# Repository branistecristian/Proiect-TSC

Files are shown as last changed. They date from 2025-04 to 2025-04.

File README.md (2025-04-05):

# OpenBook – E-Reader Hardware Project

OpenBook is an open-source e-reader built around the ESP32-C6, featuring a 7.5" e-Paper display, rechargeable battery, and Wi-Fi support. Designed for low-power embedded use and comfortable digital reading.

---

##  Block Diagram

`Images/block_diagram.png`

> Diagram shows how ESP32-C6 is connected to display, battery, charging module, and buttons.

---

## 📋 Bill of Materials (BOM)

| Reference | Value | Device | Footprint | Description | Link |
|:---|:---|:---|:---|:---|:---|
| BOOT_BUTTON  | BUTTON_CUSYOMV1  | BUTTON_CUSYOMV1 | MYBUTTON | - | https://industry.panasonic.com/global/en/products/control/switch/light-touch/number/evqpuj02k |
| C1 | 100nF | ESP32_WROVER_EAGLE-LTSPICE_CC0402 | C0402 | CAPACITOR, European symbol | https://componentsearchengine.com/part-view/CC0402MRX5R5BB106/YAGEO |
| C2 | 100nF | ESP32_WROVER_EAGLE-LTSPICE_CC0402 | C0402 | CAPACITOR, European symbol | |
| C3 | 100uF TANT | RCL_CPOL-EUCT3528 | CT3528 | POLARIZED CAPACITOR | |
| C10_SUPERCAP | CPH3225A | CPH3225A | CAPCP3225X100N | 11 mF (EDLC) Supercapacitor 3.3V | https://www.snapeda.com/parts/CPH3225A/Seiko+Instruments/view-part/?ref=eda |
| CHG_LED | - | ADAFRUIT_LEDCHIP-LED0603 | LED0603 | LED | https://www.snapeda.com/parts/KP-1608SURCK/Kingbright/view-part/?ref=search&t=LED |
| D1 | USBLC6-2SC6Y | USBLC6-2SC6Y | SOT23-6 | TVS Diode Array | https://www.snapeda.com/parts/USBLC6-2SC6Y/STMicroelectronics/view-part/?ref=eda |
| D2 | - | AVX_SD0805S020S1R0 | 0805 | Schottky Diode | https://eu.mouser.com/ProductDetail/KYOCERA-AVX/SD0805S020S1R0 |
| D3 | MBR0530 | MBR0530 | SOD123 | Schottky Diode | https://www.snapeda.com/parts/MBR0530/Onsemi/view-part/?ref=eda |
| D4 | MBR0530 | MBR0530 | SOD123 | Schottky Diode | https://www.snapeda.com/parts/MBR0530/Onsemi/view-part/?ref=eda |
| D5 | MBR0530 | MBR0530 | SOD123 | Schottky Diode | https://www.snapeda.com/parts/MBR0530/Onsemi/view-part/?ref=eda |
| D6 | PGB1010603MR | PGB1010603MR | 0603 | TVS Diode Clamp | https://www.snapeda.com/parts/PGB1010603MR/Littelfuse/view-part/?ref=eda |
| D7 | - | AVX_SD0805S020S1R0 | 0805 | Schottky Diode | https://eu.mouser.com/ProductDetail/KYOCERA-AVX/SD0805S020S1R0 |
| D8 | PGB1010603MR | PGB1010603MR | 0603 | TVS Diode Clamp | https://www.snapeda.com/parts/PGB1010603MR/Littelfuse/view-part/?ref=eda |
| D9 | PGB1010603MR | PGB1010603MR | 0603 | TVS Diode Clamp | https://www.snapeda.com/parts/PGB1010603MR/Littelfuse/view-part/?ref=eda |
| D10 | PGB1010603MR | PGB1010603MR | 0603 | TVS Diode Clamp | https://www.snapeda.com/parts/PGB1010603MR/Littelfuse/view-part/?ref=eda |
| D11 | PGB1010603MR | PGB1010603MR | 0603 | TVS Diode Clamp | https://www.snapeda.com/parts/PGB1010603MR/Littelfuse/view-part/?ref=eda |
| IC1 | BD5229G-TR | BD5229G-TR | SOT23-5 | Voltage Detector | https://componentsearchengine.com/part-view/BD5229G-TR/ROHM%20Semiconductor |
| IC4 | XC6220A331MR-G | XC6220A331MR-G | SOT23-5 | LDO Regulator | https://componentsearchengine.com/part-view/XC6220A331MR-G/Torex |
| J1 | FFC 24P | FH34SRJ-24S-0.5SH | 0.5mm Pitch | FFC/FPC Connector | https://componentsearchengine.com/part-view/FH34SRJ-24S-0.5SH(99)/Hirose |
| J2 | USB-C | USB4110-GF-A | USB4110 | USB Type-C Connector | https://componentsearchengine.com/part-view/USB4110-GF-A/GCT%20(GLOBAL%20CONNECTOR%20TECHNOLOGY) |
| J3 | QWIIC | QWIIC_CONNECTORJS-1MM | JST04 | QWIIC I2C Connector | |
| J4 | SD Card | 112A-TAAR-R03_ATTEND | MicroSD | MicroSD Socket | https://store.comet.srl.ro/Catalogue/Product/43497/ |
| L1 | 68uH | 744043680 | IND_4828 | Power Inductor | https://eu.mouser.com/ProductDetail/Wurth-Elektronik/744043680 |
| PFMF.050.1 | - | ESP32C6_VARISTOR | 1812 | Varistor | https://www.mouser.co.uk/ProductDetail/EPCOS-TDK/B72520T0350K062 |
| Q1 | - | DMG2305UX-7 | SOT23 | P-channel MOSFET | https://componentsearchengine.com/part-view/DMG2305UX-7/Diodes%20Incorporated |
| Q2 | - | DMG2305UX-7 | SOT23 | P-channel MOSFET | |
| Q3 | SI1308EDL-T1-GE3 | SI1308EDL | SC70 | N-channel MOSFET | https://componentsearchengine.com/part-view/SI1308EDL-T1-GE3/Vishay |
| R1 | 10K | ESP32_WROVER_EAGLE-LTSPICE_RR0402 | R0402 | RESISTOR | |
| R2 | 2.2 | ESP32_WROVER_EAGLE-LTSPICE_RR0402 | R0402 | RESISTOR | https://componentsearchengine.com/part-view/R0402%201%25%20100%20K%20(RC0402FR-07100KL)/YAGEO |

---

##  Detailed Hardware Functionality

###  Power System
- 3.7V 1800mAh Li-Po Battery (Cellevia LP584174)
- Charged via TP4056 USB module
- 3.3V provided via AMS1117 LDO regulator

###  Display
- Waveshare 7.5" e-Paper V2, SPI interface
- 800x480 resolution, ultra-low power
- Controlled by ESP32-C6 using GPIOs

###  Microcontroller – ESP32-C6
- BLE 5 + Wi-Fi 6
- Handles display updates and user input
- SPI + UART + GPIO used

###  Estimated Power Budget
| State | Current | Est. Battery Life (1800mAh) |
|---|---|---|
| Idle | ~20mA | ~90 hours |
| Display Update  | ~120mA  | ~12–15 hours |

##  ESP32-C6 Pin Mapping

| Feature | ESP32-C6 Pin | Description |
|---|---|---|
| SPI CLK | GPIO6 | Display SCK |
| SPI MOSI | GPIO7 | Display data |
| Display CS | GPIO10 | Chip select |
| Display DC | GPIO5 | Command/data |
| Display RST | GPIO4 | Reset |
| Display BUSY | GPIO3 | Ready state |
| Button A | GPIO0 | Pull-down |
| Button B | GPIO1 | Pull-down |
| UART TX | GPIO21 | Debug |
| UART RX | GPIO20 | Debug |

---

##  Renders & Images

 See `Images/` folder:
- `render_device.png` – Full device
- `render_pcb.png` – PCB only
- `block_diagram.png` – System layout

---

##  Design Notes
- All components were placed in Fusion 360 with correct dimensions
- PCB designed in Eagle + validated via 3D overlay
- Gerbers, BOM, and Pick & Place ready for fab
- Fusion file exported as both `.step` and `.f3d`

---

## Credits

Made with CAD, curse words, and caffeine.

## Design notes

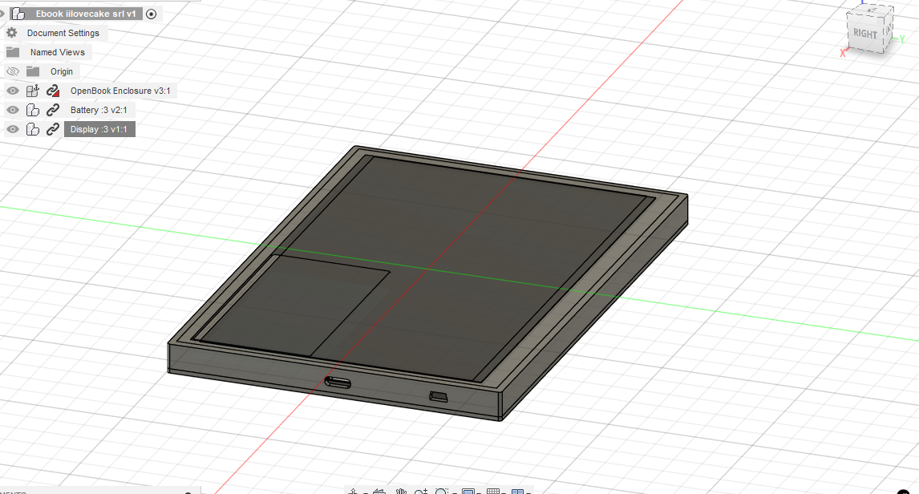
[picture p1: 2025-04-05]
Images/render_device.png

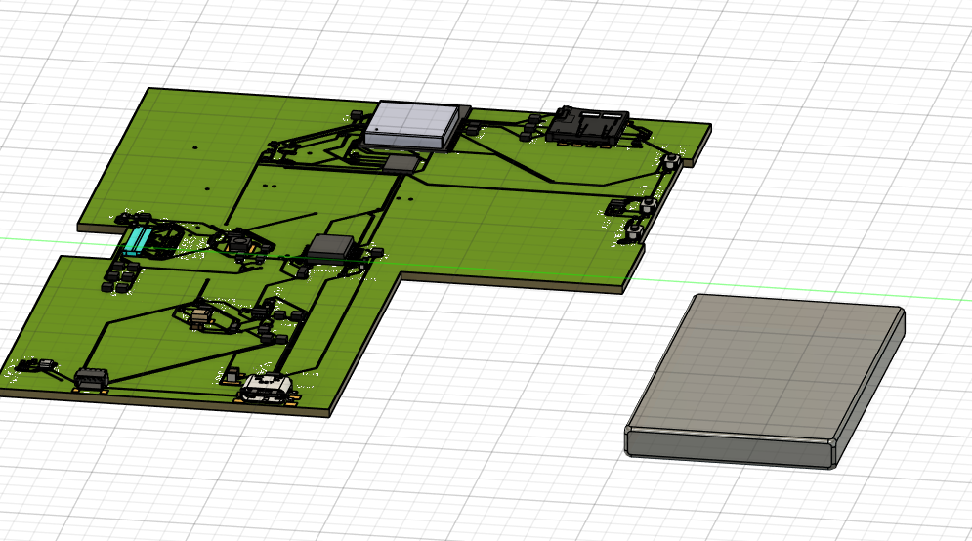
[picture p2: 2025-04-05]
Images/render_exploded.png

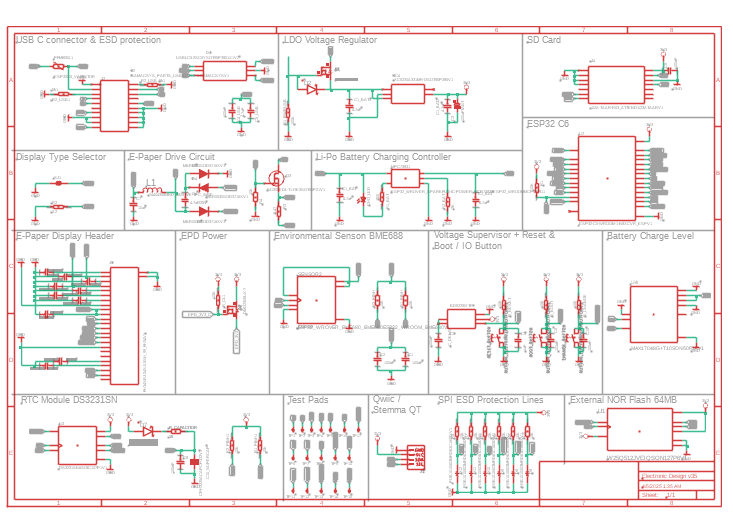
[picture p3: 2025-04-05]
Images/render_sch.png

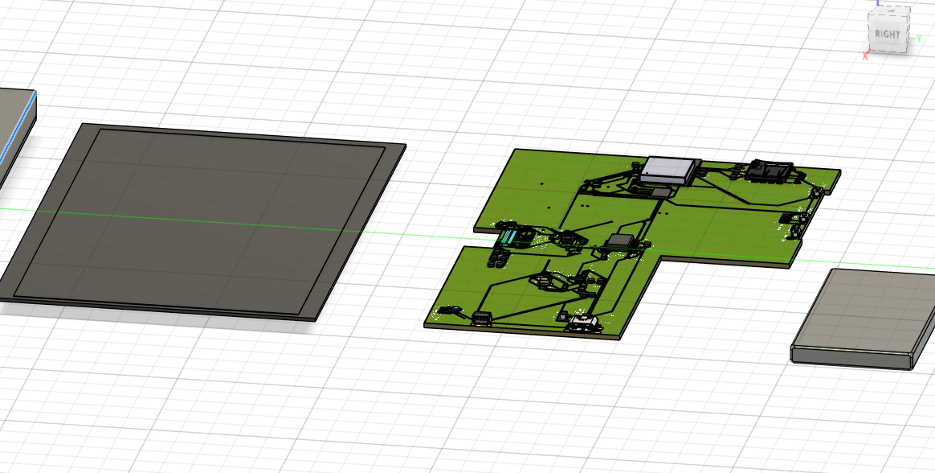
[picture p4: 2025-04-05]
Images/render_exploded1.png

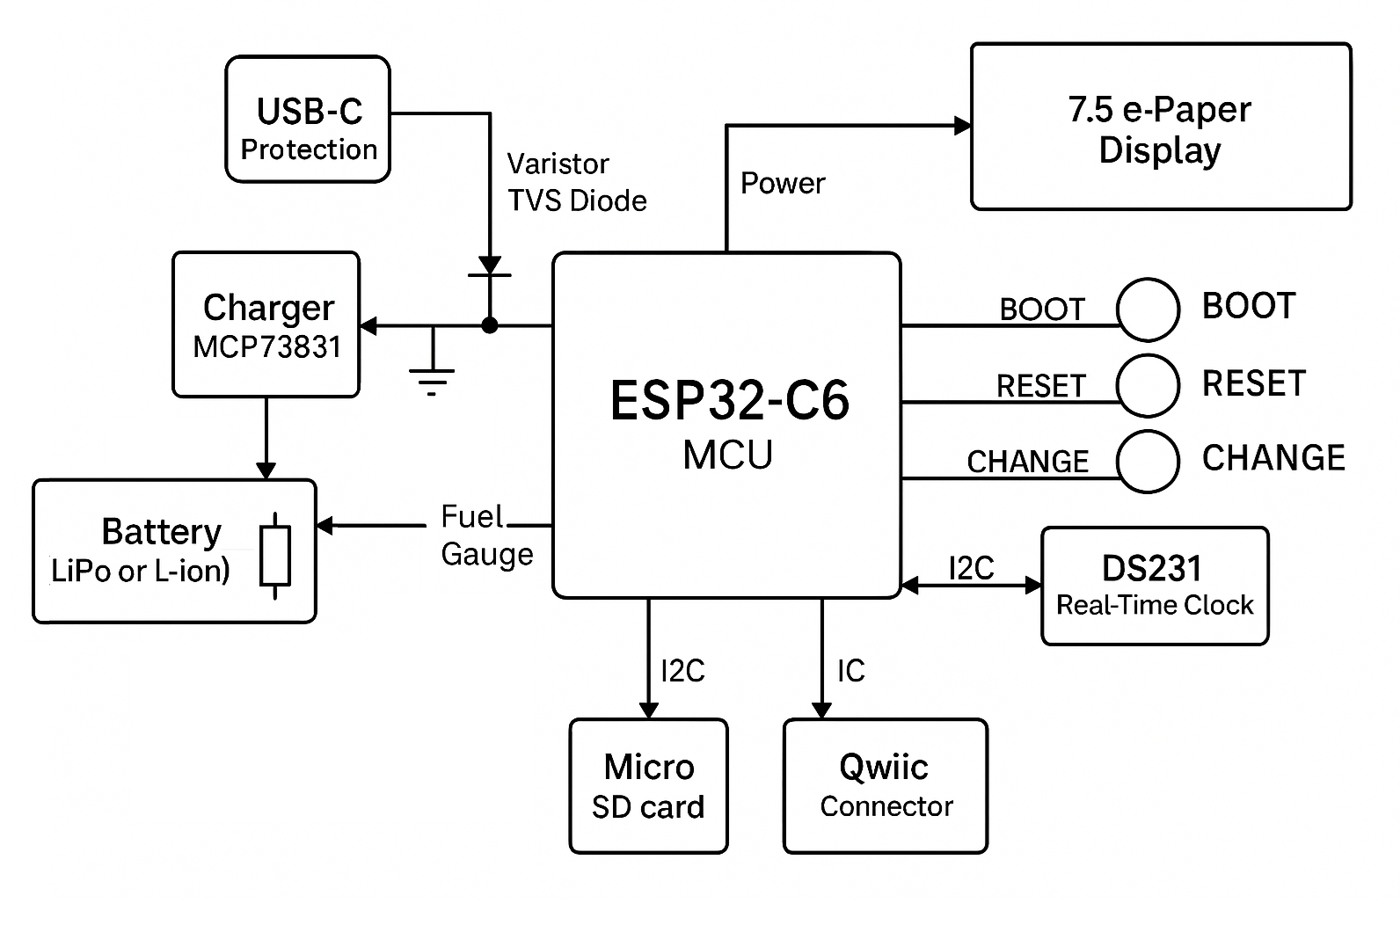
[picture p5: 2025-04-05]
Images/block_diagram.png

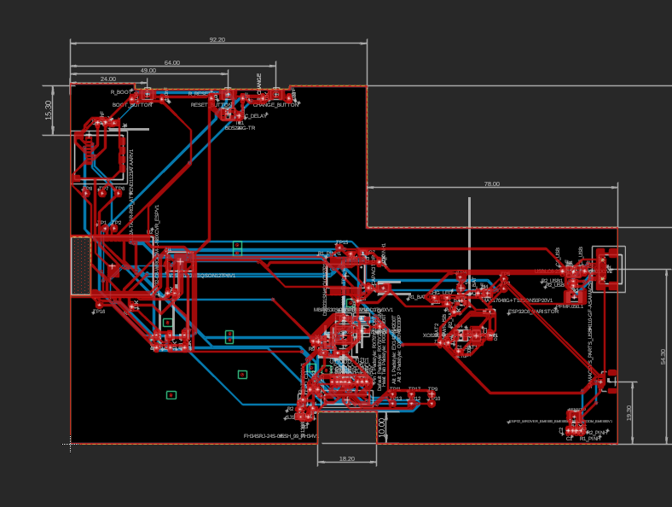
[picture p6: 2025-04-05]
Images/render_pcb.png

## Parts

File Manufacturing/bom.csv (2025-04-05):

Part | Value | Device | Footprint Name | Detailed Description | POPULARITY | SPICEMODEL | SPICEPREFIX | TP_SIGNAL_NAME
BOOT_BUTTON | BUTTON_CUSYOMV1MYBUTTONV1 | BUTTON_CUSYOMV1MYBUTTONV1 | MYBUTTON
C1 | 100nF | EAGLE-LTSPICE_CC0402 | EAGLE-LTSPICE_C0402 | CAPACITOR, European symbol |  | NONE | C
C1_BAT | 4.7uF | ESP32_WROVER_EAGLE-LTSPICE_C | ESP32_WROVER_EAGLE-LTSPICE_C0402 | CAPACITOR, European symbol
C1_BAT1 | 4.7uF | ESP32_WROVER_EAGLE-LTSPICE_C | ESP32_WROVER_EAGLE-LTSPICE_C0402 | CAPACITOR, European symbol
C1_BAT2 | 4.7uF | ESP32_WROVER_EAGLE-LTSPICE_C | ESP32_WROVER_EAGLE-LTSPICE_C0402 | CAPACITOR, European symbol
C2 | 100nF | EAGLE-LTSPICE_CC0402 | EAGLE-LTSPICE_C0402 | CAPACITOR, European symbol |  | NONE | C
C2_BAT | 4.7uF | ESP32_WROVER_EAGLE-LTSPICE_C | ESP32_WROVER_EAGLE-LTSPICE_C0402 | CAPACITOR, European symbol
C3 | 100uF TANT | RCL_CPOL-EU | RCL_CT3528 | POLARIZED CAPACITOR, European symbol
C4 | 4.7uF/25V | ESP32_WROVER_EAGLE-LTSPICE_C | ESP32_WROVER_EAGLE-LTSPICE_C0402 | CAPACITOR, European symbol
C4_USB | 100nF | ESP32_WROVER_EAGLE-LTSPICE_C | ESP32_WROVER_EAGLE-LTSPICE_C0402 | CAPACITOR, European symbol
C5 | 1uF | EAGLE-LTSPICE_CC0402 | EAGLE-LTSPICE_C0402 | CAPACITOR, European symbol |  | NONE | C
C5_USB | 4.7uF | ESP32_WROVER_EAGLE-LTSPICE_C | ESP32_WROVER_EAGLE-LTSPICE_C0402 | CAPACITOR, European symbol
C6 | 100nF | EAGLE-LTSPICE_CC0402 | EAGLE-LTSPICE_C0402 | CAPACITOR, European symbol |  | NONE | C
C7 | 10uF | ESP32_WROVER_EAGLE-LTSPICE_C | ESP32_WROVER_EAGLE-LTSPICE_C0402 | CAPACITOR, European symbol
C8 | 100nF | EAGLE-LTSPICE_CC0402 | EAGLE-LTSPICE_C0402 | CAPACITOR, European symbol |  | NONE | C
C9 | 100nF | ESP32_WROVER_EAGLE-LTSPICE_C | ESP32_WROVER_EAGLE-LTSPICE_C0402 | CAPACITOR, European symbol
C10 | 100nF | EAGLE-LTSPICE_CC0402 | EAGLE-LTSPICE_C0402 | CAPACITOR, European symbol |  | NONE | C
C10_SUPERCAP | CPH3225ACAPCP322V1 | CPH3225ACAPCP322V1 | CAPCP3225X100N | Cap 0.011F 3.3V 1210 Flat Check availability
CHANGE_BUTTON | BUTTON_CUSYOMV1MYBUTTONV1 | BUTTON_CUSYOMV1MYBUTTONV1 | MYBUTTON
CHG_LED |  | ADAFRUIT_LED | ADAFRUIT_CHIP-LED0603 | LED
C_DELAY | 100nF | EAGLE-LTSPICE_CC0402 | EAGLE-LTSPICE_C0402 | CAPACITOR, European symbol |  | NONE | C
D1 | USBLC6-2SC6YSOT95P2801X1V2 | USBLC6-2SC6YSOT95P2801X1V2 | SOT95P280X145-6N | Low Cap. ESD Protection Auto SOT-23-6 STMicroelectronics USBLC6-2SC6Y, Dual Uni-Directional TVS Diode Array, 6-Pin SOT-23
D2 | ESP32_WROVER_AVX---SD0805S020S1R0_AVX_SD0805S020S1R0_0_0 | ESP32_WROVER_AVX---SD0805S020S1R0_AVX_SD0805S020S1R0_0_0 | ESP32_WROVER_AVX---SD0805S020S1R0_AVX_SD0805S020S1R0_0 | Schottky Barrier Rectifier Diode
D3 | MBR0530SOD3716XV1 | MBR0530SOD3716XV1 | SOD3716X135N | ON SEMICONDUCTOR - MBR0530 - DIODE, SCHOTTKY, 0.5A, 30V, SOD-123
D4 | MBR0530SOD3716XV1 | MBR0530SOD3716XV1 | SOD3716X135N | ON SEMICONDUCTOR - MBR0530 - DIODE, SCHOTTKY, 0.5A, 30V, SOD-123
D5 | MBR0530SOD3716XV1 | MBR0530SOD3716XV1 | SOD3716X135N | ON SEMICONDUCTOR - MBR0530 - DIODE, SCHOTTKY, 0.5A, 30V, SOD-123
D6 | PGB1010603MRDIOC1608XV1 | PGB1010603MRDIOC1608XV1 | DIOC1608X36N | Check availability
D7 | ESP32_WROVER_AVX---SD0805S020S1R0_AVX_SD0805S020S1R0_0_0 | ESP32_WROVER_AVX---SD0805S020S1R0_AVX_SD0805S020S1R0_0_0 | ESP32_WROVER_AVX---SD0805S020S1R0_AVX_SD0805S020S1R0_0 | Schottky Barrier Rectifier Diode
D8 | PGB1010603MRDIOC1608XV1 | PGB1010603MRDIOC1608XV1 | DIOC1608X36N | Check availability
D9 | PGB1010603MRDIOC1608XV1 | PGB1010603MRDIOC1608XV1 | DIOC1608X36N | Check availability
D10 | PGB1010603MRDIOC1608XV1 | PGB1010603MRDIOC1608XV1 | DIOC1608X36N | Check availability
D11 | PGB1010603MRDIOC1608XV1 | PGB1010603MRDIOC1608XV1 | DIOC1608X36N | Check availability
D12 | PGB1010603MRDIOC1608XV1 | PGB1010603MRDIOC1608XV1 | DIOC1608X36N | Check availability
EPD_C1 | 1uF/50V | EAGLE-LTSPICE_CC0402 | EAGLE-LTSPICE_C0402 | CAPACITOR, European symbol |  | NONE | C
EPD_C2 | 1uF/50V | EAGLE-LTSPICE_CC0402 | EAGLE-LTSPICE_C0402 | CAPACITOR, European symbol |  | NONE | C
EPD_C5 | 0.1uF/50V | EAGLE-LTSPICE_CC0402 | EAGLE-LTSPICE_C0402 | CAPACITOR, European symbol |  | NONE | C
EPD_C6 | 1uF/50V | EAGLE-LTSPICE_CC0402 | EAGLE-LTSPICE_C0402 | CAPACITOR, European symbol |  | NONE | C
EPD_C7 | 1uF/50V | EAGLE-LTSPICE_CC0402 | EAGLE-LTSPICE_C0402 | CAPACITOR, European symbol |  | NONE | C
EPD_C8 | 1uF/50V | EAGLE-LTSPICE_CC0402 | EAGLE-LTSPICE_C0402 | CAPACITOR, European symbol |  | NONE | C
EPD_C9 | 1uF/50V | EAGLE-LTSPICE_CC0402 | EAGLE-LTSPICE_C0402 | CAPACITOR, European symbol |  | NONE | C
EPD_C10 | 1uF/50V | EAGLE-LTSPICE_CC0402 | EAGLE-LTSPICE_C0402 | CAPACITOR, European symbol |  | NONE | C
EPD_C11 | 1uF/50V | EAGLE-LTSPICE_CC0402 | EAGLE-LTSPICE_C0402 | CAPACITOR, European symbol |  | NONE | C
EPD_C12 | 1uF/50V | EAGLE-LTSPICE_CC0402 | EAGLE-LTSPICE_C0402 | CAPACITOR, European symbol |  | NONE | C
IC1 | BD5229G-TR | BD5229G-TR | SOT95P280X120-5N | Voltage Detector with Adjustable Delay Time: CMOS processes are utilized to develop high precision, low current consumption CMOS reset ICs that allow arbitrary setting of the delay time. The extensive lineup includes both Nch Open Drain and CMOS output types in a wide range of detection voltages (from 2.3V to 6.0V, in 0.1V steps), enabling selection of the ideal solution based on customer requirements. In addition, the entire series is of course both lead-free and RoHS-compliant.
IC4 | XC6220A331MR-GSOT95P285V1 | XC6220A331MR-GSOT95P285V1 | SOT95P280X120-5N | LDO Voltage Regulators
J1 | FH34SRJ-24S-0.5SH_99_FH34V1 | FH34SRJ-24S-0.5SH_99_FH34V1 | FH34SRJ24S05SH99 | 24 Position FFC, FPC Connector Contacts, Top and Bottom 0.020 (0.50mm) Surface Mount, Right Angle"
J2 | SAMACSYS_PARTS_USB4110-GF-ASAMACSYSV1 | SAMACSYS_PARTS_USB4110-GF-ASAMACSYSV1 | SAMACSYS_PARTS_USB4110GFA | CONN USB 2.0 TYPE-C R/A SMT
J3 | QWIIC_RIGHT_ANGLE | QWIIC_CONNECTOR | JST04_1MM_RA | SparkFun I2C Standard Qwiic Connector
J4 | 112A-TAAR-R03_ATTEND1123ATAARV1 | 112A-TAAR-R03_ATTEND1123ATAARV1 | 112ATAARR03ATTEND | Micro SD Card Socket, Push-Push Type, Top Mount, SMT, H=1.83mm, 10u
L1 | 744043680IND_4828-WE-TPC_WRE | 744043680 | IND_4828-WE-TPC_WRE
MPC73831 | ESP32_WROVER_SPARKFUN-IC-POWER_MCP73831ESP32_WROOMMCP673811 | ESP32_WROVER_SPARKFUN-IC-POWER_MCP73831ESP32_WROOMMCP673811 | ESP32_WROVER_SPARKFUN-IC-POWER_SOT23-5 | MCP73831T Li-Ion, Li-Pol Controller
PFMF.050.1 | ESP32C6_VARISTOR | ESP32C6_VARISTOR | ESP32C6_VARISTOR_CT/CN1812 | VARISTOR
Q1 | 20V/4.2A/52mO/1.4W | ESP32_WROVER_SPARKFUN-DISCRETESEMI_MOSFET_PCH | ESP32_WROVER_SPARKFUN-DISCRETESEMI_SOT23-3 | P-channel MOSFETs
Q2 | 20V/4.2A/52mO/1.4W | ESP32_WROVER_SPARKFUN-DISCRETESEMI_MOSFET_PCH | ESP32_WROVER_SPARKFUN-DISCRETESEMI_SOT23-3 | P-channel MOSFETs
Q3 | SI1308EDL-T1-GE3SOT65P21V1 | SI1308EDL-T1-GE3SOT65P21V1 | SOT65P210X110-3N | MOSFET N-Ch 30V 1.5A TrenchFET SC70 Vishay Si1308EDL-T1-GE3 N-channel MOSFET Transistor, 1.5 A, 30 V, 3-Pin SC-70
R1 | 10K | ESP32_WROVER_EAGLE-LTSPICE_R | ESP32_WROVER_EAGLE-LTSPICE_R0402 | RESISTOR, European symbol
R1_BAT | 200 | ESP32_WROVER_EAGLE-LTSPICE_R | ESP32_WROVER_EAGLE-LTSPICE_R0402 | RESISTOR, European symbol
R1_PINH | 10K | ESP32_WROVER_EAGLE-LTSPICE_R | ESP32_WROVER_EAGLE-LTSPICE_R0402 | RESISTOR, European symbol
R1_PINH1 | 10K | ESP32_WROVER_EAGLE-LTSPICE_R | ESP32_WROVER_EAGLE-LTSPICE_R0402 | RESISTOR, European symbol
R1_PWRUSB | 100K | ESP32_WROVER_EAGLE-LTSPICE_R | ESP32_WROVER_EAGLE-LTSPICE_R0402 | RESISTOR, European symbol
R2 | 2.2 | ESP32_WROVER_EAGLE-LTSPICE_R | ESP32_WROVER_EAGLE-LTSPICE_R0402 | RESISTOR, European symbol
R2_BAT | 2K | ESP32_WROVER_EAGLE-LTSPICE_R | ESP32_WROVER_EAGLE-LTSPICE_R0402 | RESISTOR, European symbol
R2_PINH | 10K | ESP32_WROVER_EAGLE-LTSPICE_R | ESP32_WROVER_EAGLE-LTSPICE_R0402 | RESISTOR, European symbol
R2_PINH1 | 10K | ESP32_WROVER_EAGLE-LTSPICE_R | ESP32_WROVER_EAGLE-LTSPICE_R0402 | RESISTOR, European symbol
R2_USB | 5k1 | ESP32_WROVER_EAGLE-LTSPICE_R | ESP32_WROVER_EAGLE-LTSPICE_R0402 | RESISTOR, European symbol
R2_USB1 | 5k1 | ESP32_WROVER_EAGLE-LTSPICE_R | ESP32_WROVER_EAGLE-LTSPICE_R0402 | RESISTOR, European symbol
R3 | 0.47 | ESP32_WROVER_EAGLE-LTSPICE_R | ESP32_WROVER_EAGLE-LTSPICE_R0402 | RESISTOR, European symbol
R4 | 10K | ESP32_WROVER_EAGLE-LTSPICE_R | ESP32_WROVER_EAGLE-LTSPICE_R0402 | RESISTOR, European symbol
R5 | 10K | ESP32_WROVER_EAGLE-LTSPICE_R | ESP32_WROVER_EAGLE-LTSPICE_R0402 | RESISTOR, European symbol
R6 | 10K | ESP32_WROVER_EAGLE-LTSPICE_R | ESP32_WROVER_EAGLE-LTSPICE_R0402 | RESISTOR, European symbol
R7 | 10K | ESP32_WROVER_EAGLE-LTSPICE_R | ESP32_WROVER_EAGLE-LTSPICE_R0402 | RESISTOR, European symbol
R8 | 10K | ESP32_WROVER_EAGLE-LTSPICE_R | ESP32_WROVER_EAGLE-LTSPICE_R0402 | RESISTOR, European symbol
R9 | 10K | ESP32_WROVER_EAGLE-LTSPICE_R | ESP32_WROVER_EAGLE-LTSPICE_R0402 | RESISTOR, European symbol
R10 | 10K | ESP32_WROVER_EAGLE-LTSPICE_R | ESP32_WROVER_EAGLE-LTSPICE_R0402 | RESISTOR, European symbol
RESET_BUTTON | BUTTON_CUSYOMV1MYBUTTONV1 | BUTTON_CUSYOMV1MYBUTTONV1 | MYBUTTON
R_BOOT | 10K | ESP32_WROVER_EAGLE-LTSPICE_R | ESP32_WROVER_EAGLE-LTSPICE_R0402 | RESISTOR, European symbol
R_CAPACITOR | 15 | ESP32_WROVER_EAGLE-LTSPICE_R | ESP32_WROVER_EAGLE-LTSPICE_R0402 | RESISTOR, European symbol
R_CHANGE | 10K | ESP32_WROVER_EAGLE-LTSPICE_R | ESP32_WROVER_EAGLE-LTSPICE_R0402 | RESISTOR, European symbol
R_CL1 | 10K | ESP32_WROVER_EAGLE-LTSPICE_R | ESP32_WROVER_EAGLE-LTSPICE_R0402 | RESISTOR, European symbol
R_RESET | 10K | ESP32_WROVER_EAGLE-LTSPICE_R | ESP32_WROVER_EAGLE-LTSPICE_R0402 | RESISTOR, European symbol
SENSOR2 | ESP32_WROVER_BME680_BME680ESP32_WROOM_BME680V1 | ESP32_WROVER_BME680_BME680ESP32_WROOM_BME680V1 | ESP32_WROVER_BME680_PSON80P300X300X100-8N | Integrated Environmental Unit
SJ1 |  | SJSJV1 | SJ | SMD solder JUMPER
TP1 | TPTP20R | TPTP20R | TP20R | Test pad | 2
TP2 | TPTP20R | TPTP20R | TP20R | Test pad | 2
TP3 | TPTP20R | TPTP20R | TP20R | Test pad | 2
TP4 | TPTP20R | TPTP20R | TP20R | Test pad | 2
TP5 | TPTP20R | TPTP20R | TP20R | Test pad | 2
TP6 | TPTP20R | TPTP20R | TP20R | Test pad | 2
TP7 | TPTP20R | TPTP20R | TP20R | Test pad | 2
TP8 | TPTP20R | TPTP20R | TP20R | Test pad | 2
TP9 | TPTP20R | TPTP20R | TP20R | Test pad | 2
TP10 | TPTP20R | TPTP20R | TP20R | Test pad | 2
TP11 | TPTP20R | TPTP20R | TP20R | Test pad | 2
TP12 | TPTP20R | TPTP20R | TP20R | Test pad | 2
TP13 | TPTP20R | TPTP20R | TP20R | Test pad | 2
TP14 | TPTP20R | TPTP20R | TP20R | Test pad | 2
TP15 | TPTP20R | TPTP20R | TP20R | Test pad | 2
TP16 | TPTP20R | TPTP20R | TP20R | Test pad | 2
TP17 | TPTP20R | TPTP20R | TP20R | Test pad | 2
U1 | W25Q512JVEIQSON127P6V1 | W25Q512JVEIQSON127P6V1 | SON127P600X800X80-9N | Check availability
U2 | ESP32-C6-WROOM-1-N8XCVR_ESPV1 | ESP32-C6-WROOM-1-N8XCVR_ESPV1 | XCVR_ESP32-C6-WROOM-1-N8 | Check availability
U3 | DS3231SN#SOIC127P1V1 | DS3231SN#SOIC127P1V1 | SOIC127P1032X265-16N | Real Time Clock Serial 16-Pin SOIC W T/R Check availability
U4 | MAX17048G+T10SON50P20V1 | MAX17048G+T10SON50P20V1 | SON50P200X200X80-9N | Check availability

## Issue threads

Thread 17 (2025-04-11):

Probleme cu denumirile silkscreen-ului

HoriaMoroianu, 2025-04-11:
Layer-ul de silkscreen nu este citet, iar test pad-urile nu sunt marcate cu numele semnalelor corespunzătoare.

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

Closed 2025-04-14.

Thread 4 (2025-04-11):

Clarificare conținut BOM

HoriaMoroianu, 2025-04-11:
BOM-ul din README ar trebui să includă doar componentele sau modulele utilizate, împreună cu link-uri către sursele de achiziție și datasheet-urile aferente.

Closed 2025-04-14.

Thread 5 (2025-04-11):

Diagrama bloc incompletă și inconsistentă

HoriaMoroianu, 2025-04-11:
Diagrama bloc nu include toate modulele utilizate (ex: NOR Flash, senzor) și prezintă inconsistențe în denumirea componentelor și a protocoalelor de comunicație.

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

Closed 2025-04-14.

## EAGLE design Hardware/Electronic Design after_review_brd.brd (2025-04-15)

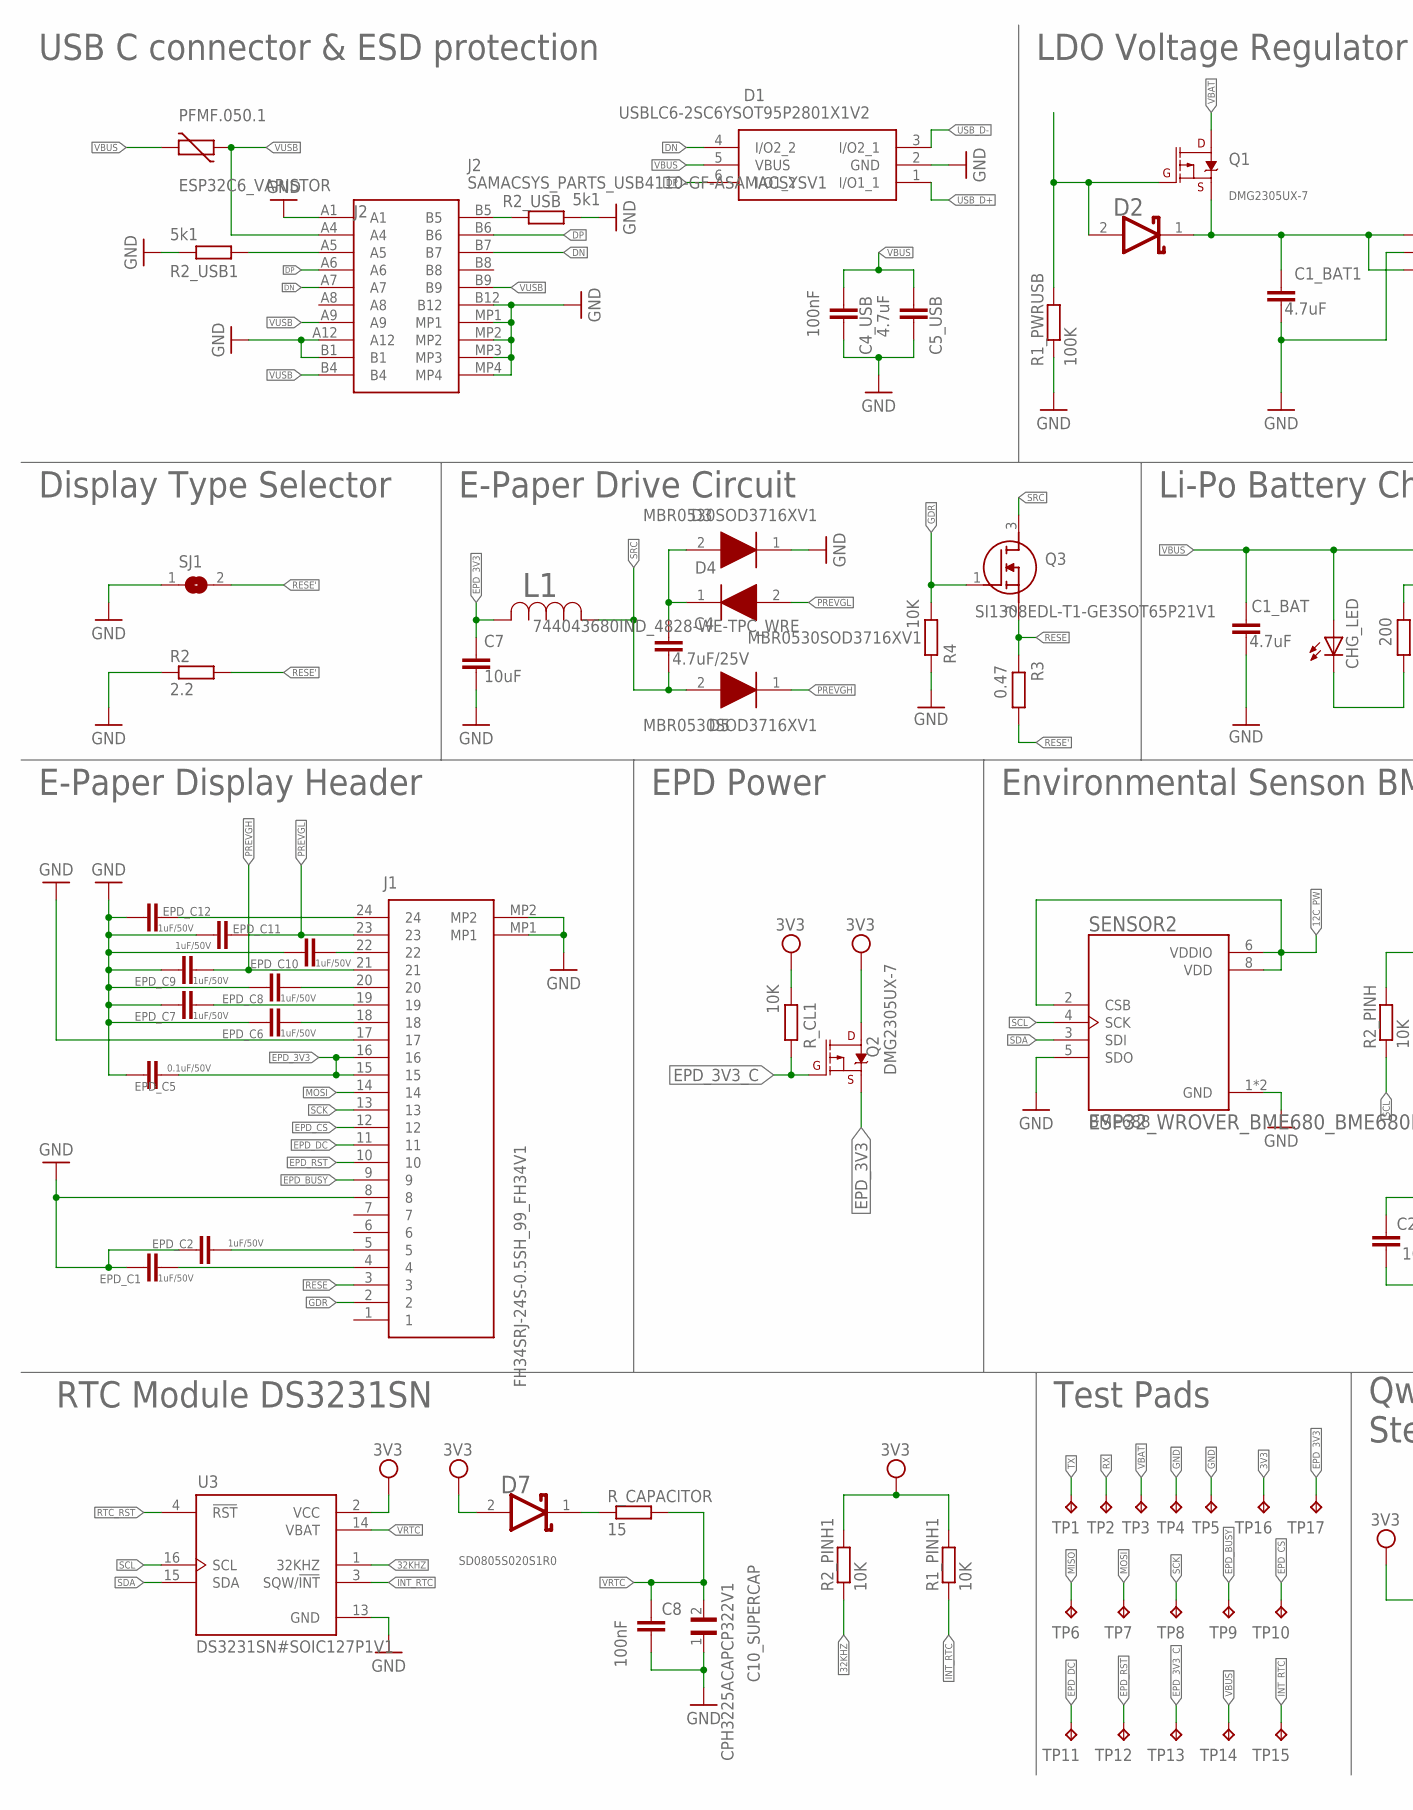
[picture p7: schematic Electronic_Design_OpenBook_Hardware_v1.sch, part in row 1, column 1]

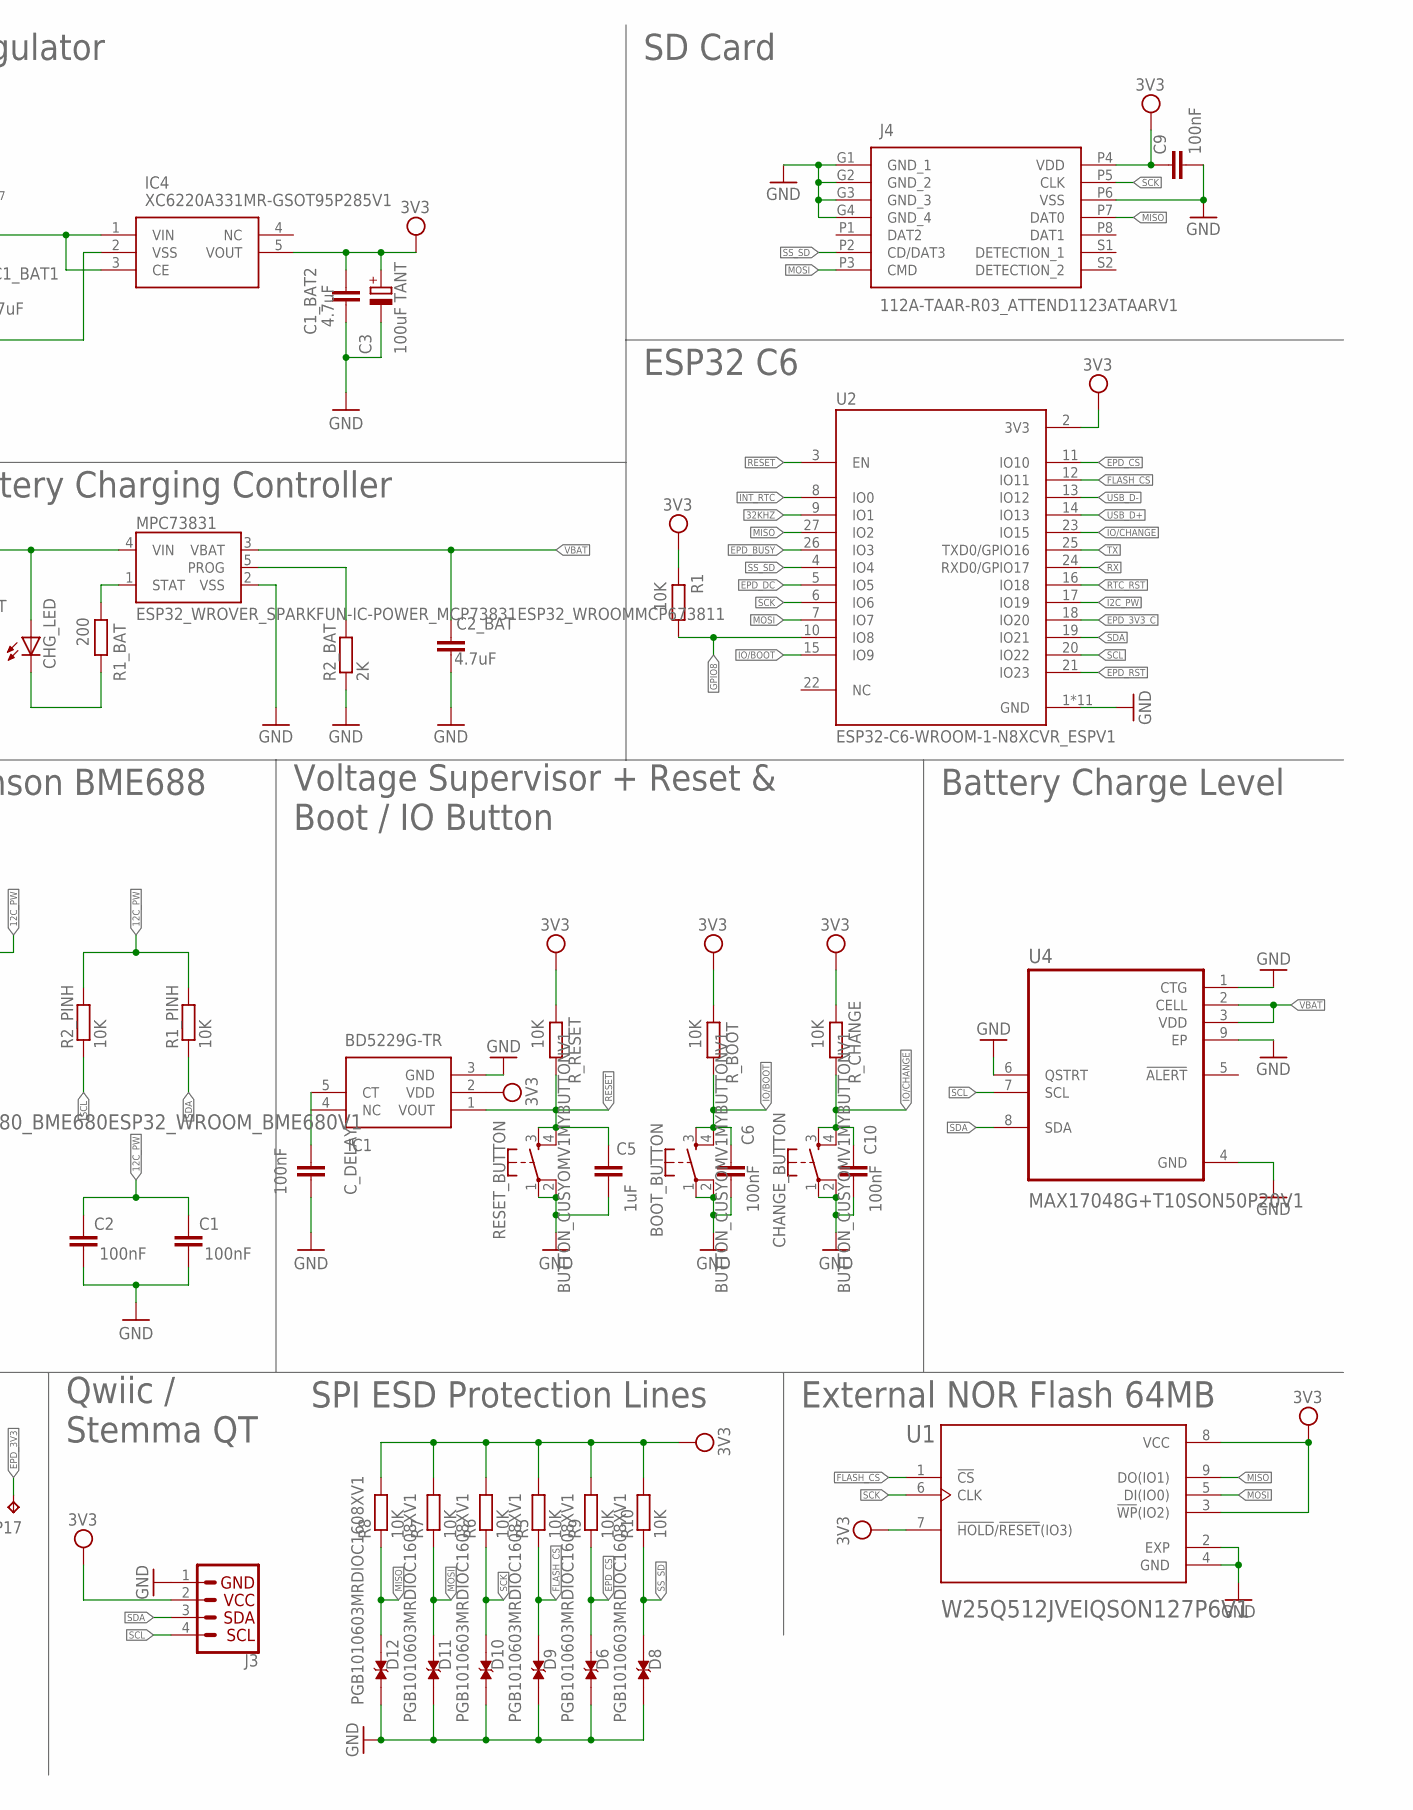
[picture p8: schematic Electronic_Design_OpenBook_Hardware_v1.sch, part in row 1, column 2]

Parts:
BOOT_BUTTON: BUTTON_CUSYOMV1MYBUTTONV1; MYBUTTON
C1, C2, C6, C8, C10: 100nF; EAGLE-LTSPICE_C0402
C1_BAT, C1_BAT1, C1_BAT2, C2_BAT, C5_USB: 4.7uF; ESP32_WROVER_EAGLE-LTSPICE_C0402
C3: 100uF TANT; RCL_CT3528
C4: 4.7uF/25V; ESP32_WROVER_EAGLE-LTSPICE_C0402
C4_USB, C9: 100nF; ESP32_WROVER_EAGLE-LTSPICE_C0402
C5: 1uF; EAGLE-LTSPICE_C0402
C7: 10uF; ESP32_WROVER_EAGLE-LTSPICE_C0402
C10_SUPERCAP: CPH3225ACAPCP322V1; CAPCP3225X100N
CHANGE_BUTTON: BUTTON_CUSYOMV1MYBUTTONV1; MYBUTTON
CHG_LED: ADAFRUIT_LED; ADAFRUIT_CHIP-LED0603
C_DELAY: 100nF; EAGLE-LTSPICE_C0402
D1: USBLC6-2SC6YSOT95P2801X1V2; SOT95P280X145-6N
D2, D7: ESP32_WROVER_AVX---SD0805S020S1R0_AVX_SD0805S020S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; ESP32_WROVER_AVX---SD0805S020S1R0_AVX_SD0805S020S1R0_0
D3, D4, D5: MBR0530SOD3716XV1; SOD3716X135N
D6, D8, D9, D10, D11, D12: PGB1010603MRDIOC1608XV1; DIOC1608X36N
EPD_C1, EPD_C2, EPD_C6, EPD_C7, EPD_C8, EPD_C9, EPD_C10, EPD_C11, EPD_C12: 1uF/50V; EAGLE-LTSPICE_C0402
EPD_C5: 0.1uF/50V; EAGLE-LTSPICE_C0402
IC1: BD5229G-TR; SOT95P280X120-5N
IC4: XC6220A331MR-GSOT95P285V1; SOT95P280X120-5N
J1: FH34SRJ-24S-0.5SH_99_FH34V1; FH34SRJ24S05SH99
J2: SAMACSYS_PARTS_USB4110-GF-ASAMACSYSV1; SAMACSYS_PARTS_USB4110GFA
J3: QWIIC_RIGHT_ANGLE; JST04_1MM_RA
J4: 112A-TAAR-R03_ATTEND1123ATAARV1; 112ATAARR03ATTEND
L1: 744043680IND_4828-WE-TPC_WRE; IND_4828-WE-TPC_WRE
MPC73831: ESP32_WROVER_SPARKFUN-IC-POWER_MCP73831ESP32_WROO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; ESP32_WROVER_SPARKFUN-IC-POWER_SOT23-5
PFMF.050.1: ESP32C6_VARISTOR; ESP32C6_VARISTOR_CT/CN1812
Q1, Q2: 20V/4.2A/52mΩ/1.4W; ESP32_WROVER_SPARKFUN-DISCRETESEMI_SOT23-3
Q3: SI1308EDL-T1-GE3SOT65P21V1; SOT65P210X110-3N
R1, R1_PINH, R1_PINH1, R2_PINH, R2_PINH1, R4, R5, R6, R7, R8, R9, R10: 10K; ESP32_WROVER_EAGLE-LTSPICE_R0402
R1_BAT: 200; ESP32_WROVER_EAGLE-LTSPICE_R0402
R1_PWRUSB: 100K; ESP32_WROVER_EAGLE-LTSPICE_R0402
R2: 2.2; ESP32_WROVER_EAGLE-LTSPICE_R0402
R2_BAT: 2K; ESP32_WROVER_EAGLE-LTSPICE_R0402
R2_USB, R2_USB1: 5k1; ESP32_WROVER_EAGLE-LTSPICE_R0402
R3: 0.47; ESP32_WROVER_EAGLE-LTSPICE_R0402
RESET_BUTTON: BUTTON_CUSYOMV1MYBUTTONV1; MYBUTTON
R_BOOT: 10K; ESP32_WROVER_EAGLE-LTSPICE_R0402
R_CAPACITOR: 15; ESP32_WROVER_EAGLE-LTSPICE_R0402
R_CHANGE: 10K; ESP32_WROVER_EAGLE-LTSPICE_R0402
R_CL1: 10K; ESP32_WROVER_EAGLE-LTSPICE_R0402
R_RESET: 10K; ESP32_WROVER_EAGLE-LTSPICE_R0402
SENSOR2: ESP32_WROVER_BME680_BME680ESP32_WROOM_BME680V1; ESP32_WROVER_BME680_PSON80P300X300X100-8N
SJ1: SJSJV1; SJ
TP1, TP2, TP3, TP4, TP5, TP6, TP7, TP8, TP9, TP10, TP11, TP12, TP13, TP14, TP15, TP16, TP17: TPTP20R; TP20R
U1: W25Q512JVEIQSON127P6V1; SON127P600X800X80-9N
U2: ESP32-C6-WROOM-1-N8XCVR_ESPV1; XCVR_ESP32-C6-WROOM-1-N8
U3: DS3231SN#SOIC127P1V1; SOIC127P1032X265-16N
U4: MAX17048G+T10SON50P20V1; SON50P200X200X80-9N

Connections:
3V3: C1_BAT2.1, C3.+, C9.1, D7.2 (ANODE), IC1.2 (VDD), IC4.5 (VOUT), J3.2, J4.P4 (VDD), Q2.3 (D), R1.2, R1_PINH1.2, R2_PINH1.2, R5.2, R6.2, R7.2, R8.2, R9.2, R10.2, R_BOOT.2, R_CHANGE.2, R_CL1.2, R_RESET.2, TP16.TP, U1.3 (!WP!(IO2)), U1.7 (!HOLD!/!RESET!(IO3)), U1.8 (VCC), U2.2 (3V3), U3.2 (VCC)
12C_PW: C1.1, C2.1, R1_PINH.2, R2_PINH.2, SENSOR2.2 (CSB), SENSOR2.6 (VDDIO), SENSOR2.8 (VDD)
32KHZ: R2_PINH1.1, U2.9 (IO1), U3.1 (32KHZ)
DN: D1.4 (I/O2_2), J2.A7, J2.B7
DP: D1.6 (I/O1_2), J2.A6, J2.B6
EPD_3V3: C7.1, EPD_C5.2, J1.15, J1.16, L1.2, Q2.2 (S), TP17.TP
EPD_3V3_C: Q2.1 (G), R_CL1.1, TP13.TP, U2.18 (IO20)
EPD_BUSY: J1.9, TP9.TP, U2.26 (IO3)
EPD_CS: D6.2, J1.12, R9.1, TP10.TP, U2.11 (IO10)
EPD_DC: J1.11, TP11.TP, U2.5 (IO5)
EPD_RST: J1.10, TP12.TP, U2.21 (IO23)
FLASH_CS: D9.2, R5.1, U1.1 (!CS), U2.12 (IO11)
GDR: J1.2, Q3.1 (G), R4.2
GND: BOOT_BUTTON.1, BOOT_BUTTON.2, C1.2, C1_BAT.2, C1_BAT1.2, C1_BAT2.2, C2.2, C2_BAT.2, C3.-, C4_USB.2, C5.2, C5_USB.2, C6.2, C7.2, C8.2, C9.2, C10.2, C10_SUPERCAP.1, CHANGE_BUTTON.1, CHANGE_BUTTON.2, C_DELAY.2, D1.2 (GND), D3.1 (K), D6.1, D8.1, D9.1, D10.1, D11.1, D12.1, EPD_C1.1, EPD_C2.1, EPD_C5.1, EPD_C6.1, EPD_C7.1, EPD_C8.1, EPD_C9.1, EPD_C10.1, EPD_C11.1, EPD_C12.1, IC1.3 (GND), IC4.2 (VSS), J1.8, J1.17, J1.MP1, J1.MP2, J2.A1, J2.A12, J2.B1, J2.B12, J2.MP1, J2.MP2, J2.MP3, J2.MP4, J3.1, J4.G1 (GND_1), J4.G2 (GND_2), J4.G3 (GND_3), J4.G4 (GND_4), J4.P6 (VSS), MPC73831.2 (VSS), R1_PWRUSB.1, R2.1, R2_BAT.1, R2_USB.2, R2_USB1.1, R4.1, RESET_BUTTON.1, RESET_BUTTON.2, SENSOR2.1 (GND), SENSOR2.5 (SDO), SENSOR2.7 (GND), SJ1.1, TP4.TP, TP5.TP, U1.2 (EXP), U1.4 (GND), U2.1 (GND), U2.28 (GND), U2.29_1 (GND), U2.29_2 (GND), U2.29_3 (GND), U2.29_4 (GND), U2.29_5 (GND), U2.29_6 (GND), U2.29_7 (GND), U2.29_8 (GND), U2.29_9 (GND), U3.13 (GND), U4.1 (CTG), U4.4 (GND), U4.6 (QSTRT), U4.9 (EP)
GPIO8: R1.1, U2.10 (IO8)
I2C_PW: U2.17 (IO19)
INT_RTC: R1_PINH1.1, TP15.TP, U2.8 (IO0), U3.3 (SQW/!INT)
IO/BOOT: BOOT_BUTTON.3, BOOT_BUTTON.4, C6.1, R_BOOT.1, U2.15 (IO9)
IO/CHANGE: C10.1, CHANGE_BUTTON.3, CHANGE_BUTTON.4, R_CHANGE.1, U2.23 (IO15)
MISO: D12.2, J4.P7 (DAT0), R8.1, TP6.TP, U1.9 (DO(IO1)), U2.27 (IO2)
MOSI: D11.2, J1.14, J4.P3 (CMD), R7.1, TP7.TP, U1.5 (DI(IO0)), U2.7 (IO7)
unnamed: J2.A5, R2_USB1.2
unnamed: C4.1, D3.2 (A), D4.1 (K)
unnamed: C_DELAY.1, IC1.5 (CT)
unnamed: CHG_LED.C, R1_BAT.1
unnamed: MPC73831.1 (STAT), R1_BAT.2
unnamed: J2.B5, R2_USB.1
unnamed: MPC73831.5 (PROG), R2_BAT.2
unnamed: EPD_C2.2, J1.5
unnamed: EPD_C1.2, J1.4
unnamed: EPD_C12.2, J1.24
unnamed: EPD_C10.2, J1.22
unnamed: EPD_C8.2, J1.20
unnamed: EPD_C7.2, J1.19
unnamed: EPD_C6.2, J1.18
unnamed: D7.1 (CATHODE), R_CAPACITOR.1
unnamed: D2.2 (ANODE), Q1.1 (G), R1_PWRUSB.2
unnamed: C1_BAT1.1, D2.1 (CATHODE), IC4.1 (VIN), IC4.3 (CE), Q1.2 (S)
PREVGH: D5.1 (K), EPD_C9.2, J1.21
PREVGL: D4.2 (A), EPD_C11.2, J1.23
RESE: J1.3, Q3.2 (S), R3.2
RESE': R2.2, R3.1, SJ1.2
RESET: C5.1, IC1.1 (VOUT), RESET_BUTTON.3, RESET_BUTTON.4, R_RESET.1, U2.3 (EN)
RTC_RST: U2.16 (IO18), U3.4 (!RST)
RX: TP2.TP, U2.24 (RXD0/GPIO17)
SCK: D10.2, J1.13, J4.P5 (CLK), R6.1, TP8.TP, U1.6 (CLK), U2.6 (IO6)
SCL: J3.4, R2_PINH.1, SENSOR2.4 (SCK), U2.20 (IO22), U3.16 (SCL), U4.7 (SCL)
SDA: J3.3, R1_PINH.1, SENSOR2.3 (SDI), U2.19 (IO21), U3.15 (SDA), U4.8 (SDA)
SRC: C4.2, D5.2 (A), L1.1, Q3.3 (D)
SS_SD: D8.2, J4.P2 (CD/DAT3), R10.1, U2.4 (IO4)
TX: TP1.TP, U2.25 (TXD0/GPIO16)
USB_D+: D1.1 (I/O1_1), U2.14 (IO13)
USB_D-: D1.3 (I/O2_1), U2.13 (IO12)
VBAT: C2_BAT.1, MPC73831.3 (VBAT), Q1.3 (D), TP3.TP, U4.2 (CELL), U4.3 (VDD)
VBUS: C1_BAT.1, C4_USB.1, C5_USB.1, CHG_LED.A, D1.5 (VBUS), MPC73831.4 (VIN), PFMF.050.1.2, TP14.TP
VRTC: C8.1, C10_SUPERCAP.2, R_CAPACITOR.2, U3.14 (VBAT)
VUSB: J2.A4, J2.A9, J2.B4, J2.B9, PFMF.050.1.1

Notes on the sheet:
USB C connector & ESD protection
Display Type Selector
E-Paper Display Header
RTC Module DS3231SN
SD0805S020S1R0
LDO Voltage Regulator
DMG2305UX-7
E-Paper Drive Circuit
EPD Power
Environmental Senson BME688
BME688
Test Pads
Qwiic / Stemma QT
SPI ESD Protection Lines
External NOR Flash 64MB
Voltage Supervisor + Reset & Boot / IO Button
Battery Charge Level
Li-Po Battery Charging Controller
SD Card
ESP32 C6

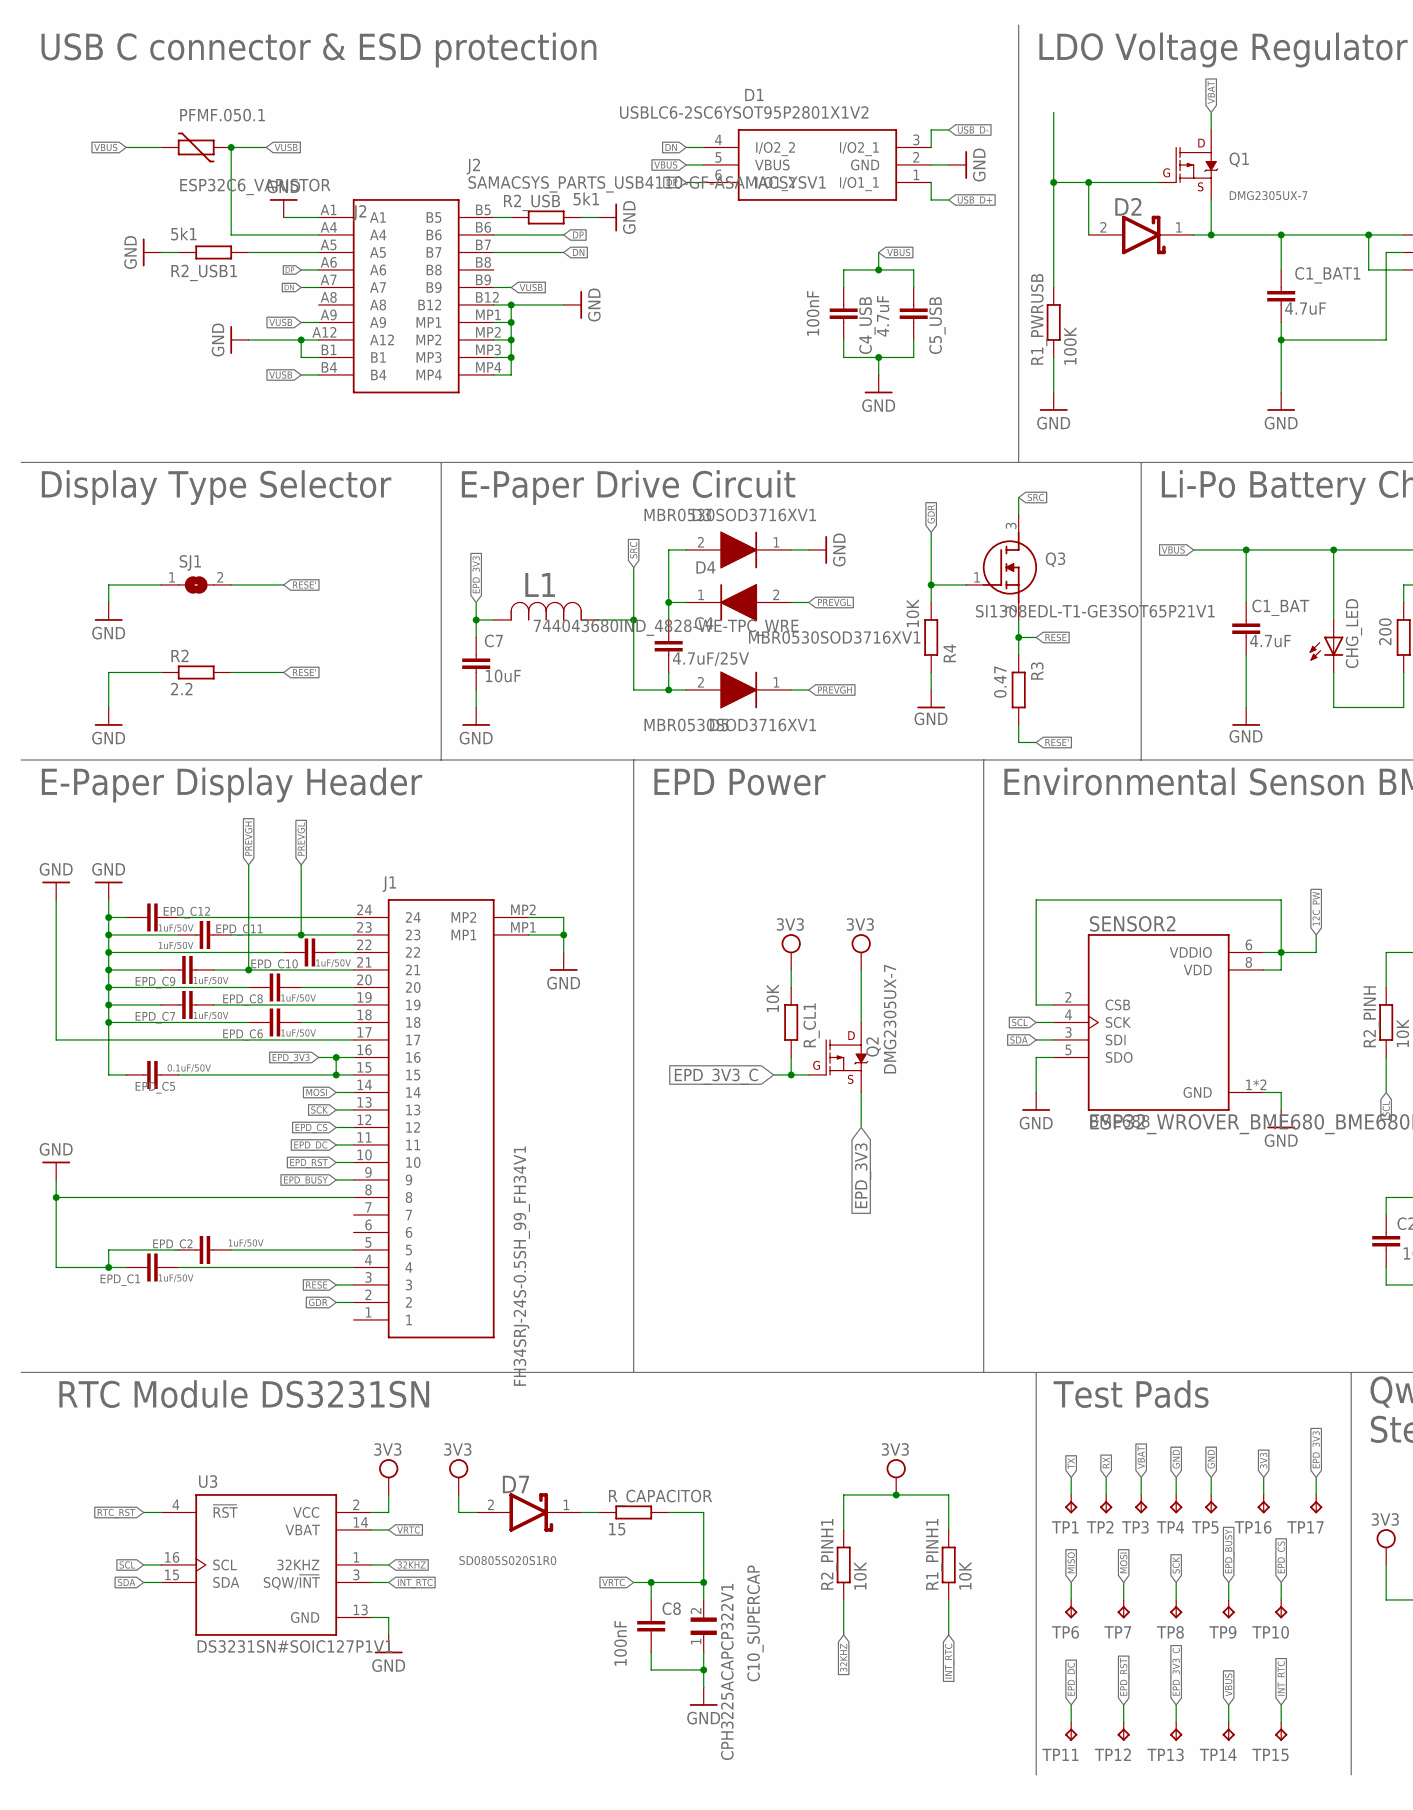
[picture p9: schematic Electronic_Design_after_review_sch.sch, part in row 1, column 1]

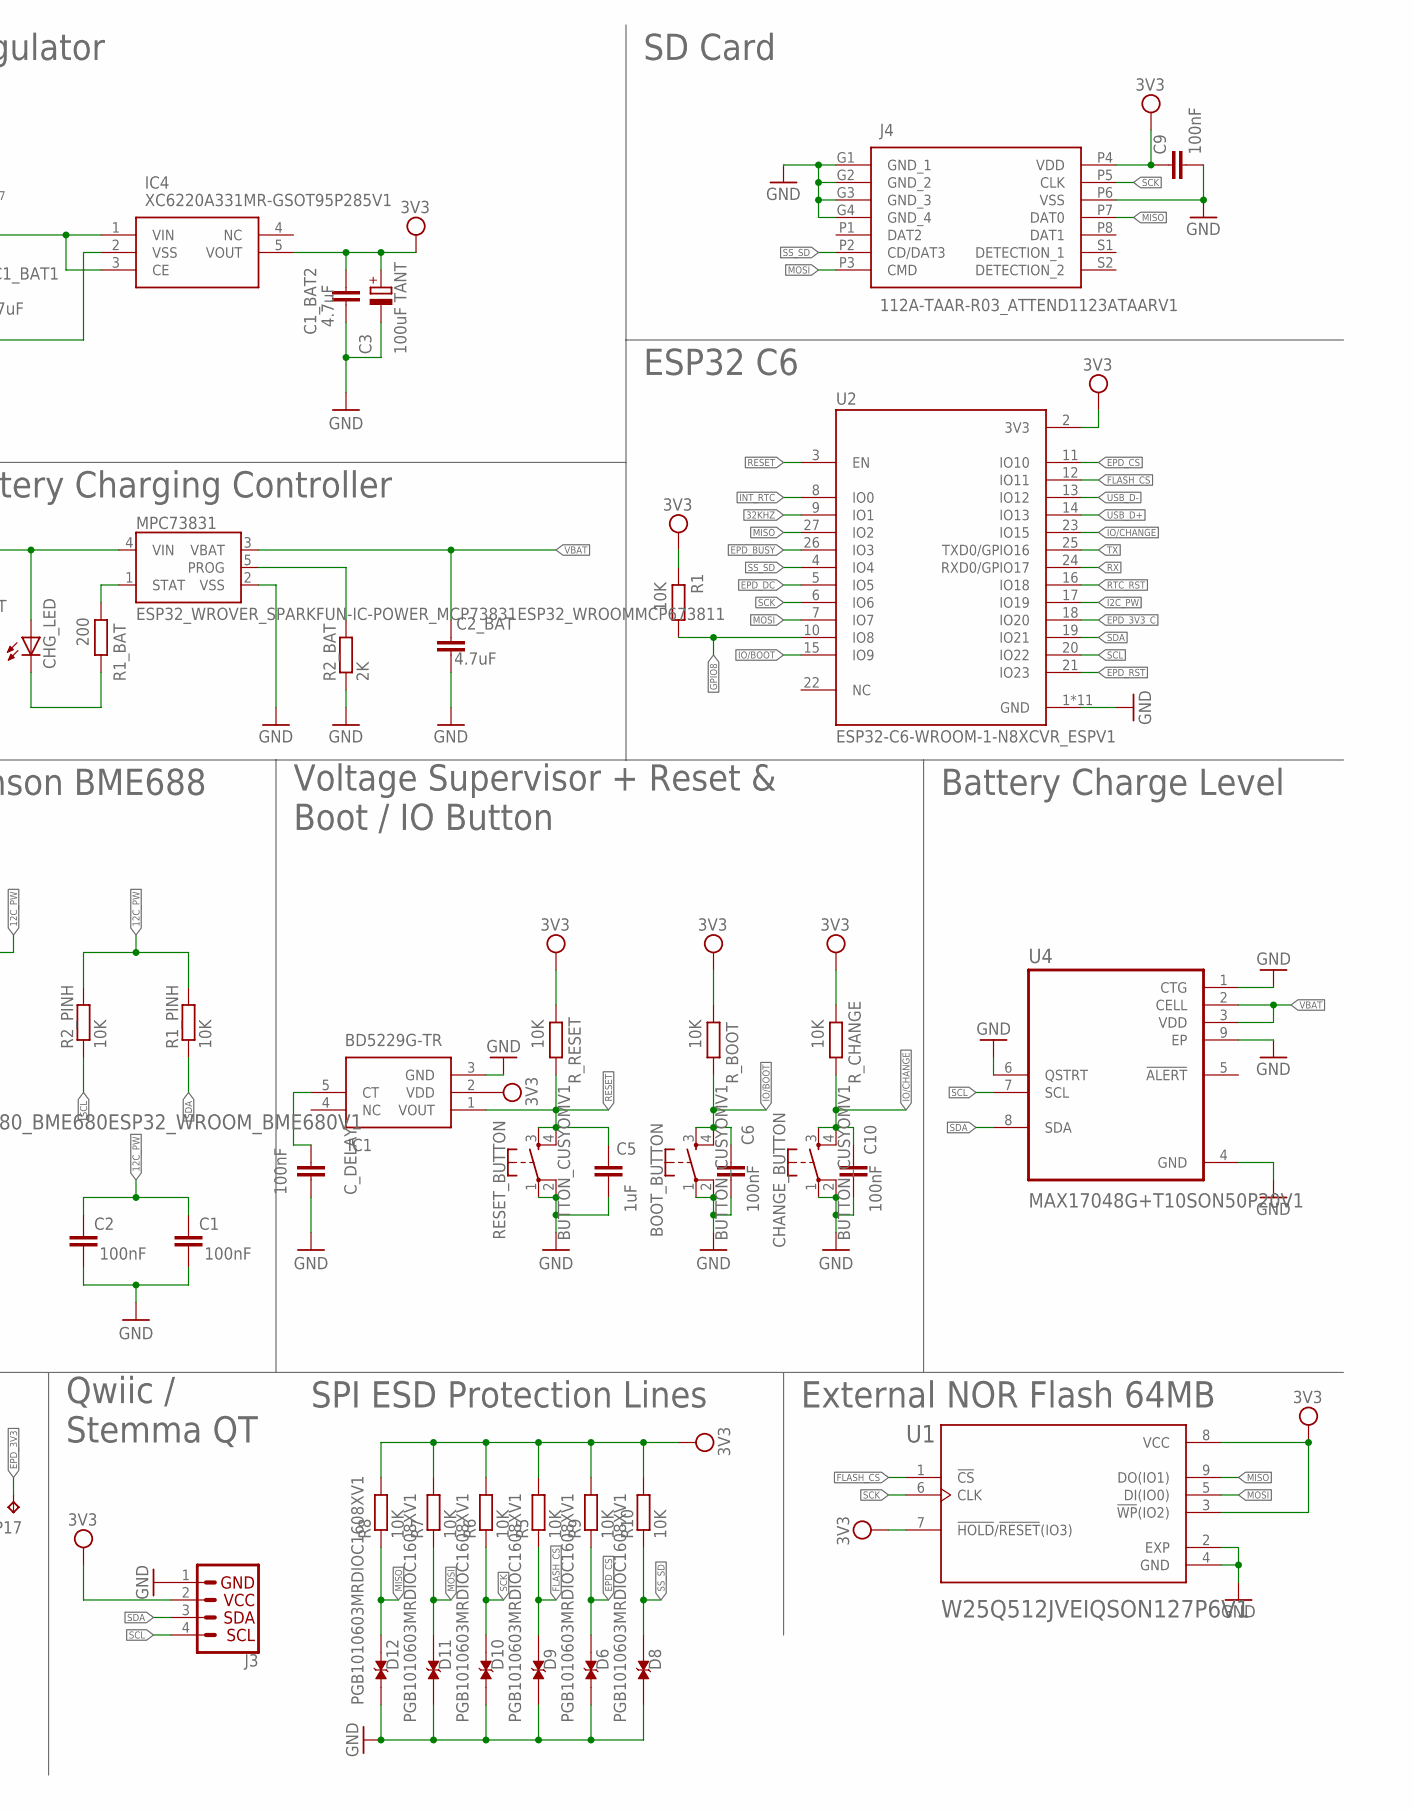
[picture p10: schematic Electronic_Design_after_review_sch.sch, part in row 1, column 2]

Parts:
BOOT_BUTTON: BUTTON_CUSYOMV1; MYBUTTON
C1, C2, C6, C8, C10: 100nF; EAGLE-LTSPICE_C0402
C1_BAT, C1_BAT1, C1_BAT2, C2_BAT, C5_USB: 4.7uF; ESP32_WROVER_EAGLE-LTSPICE_C0402
C3: 100uF TANT; RCL_CT3528
C4: 4.7uF/25V; ESP32_WROVER_EAGLE-LTSPICE_C0402
C4_USB, C9: 100nF; ESP32_WROVER_EAGLE-LTSPICE_C0402
C5: 1uF; EAGLE-LTSPICE_C0402
C7: 10uF; ESP32_WROVER_EAGLE-LTSPICE_C0402
C10_SUPERCAP: CPH3225ACAPCP322V1; CAPCP3225X100N
CHANGE_BUTTON: BUTTON_CUSYOMV1; MYBUTTON
CHG_LED: ADAFRUIT_LED; ADAFRUIT_CHIP-LED0603
C_DELAY: 100nF; EAGLE-LTSPICE_C0402
D1: USBLC6-2SC6YSOT95P2801X1V2; SOT95P280X145-6N
D2, D7: ESP32_WROVER_AVX---SD0805S020S1R0_AVX_SD0805S020S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; ESP32_WROVER_AVX---SD0805S020S1R0_AVX_SD0805S020S1R0_0
D3, D4, D5: MBR0530SOD3716XV1; SOD3716X135N
D6, D8, D9, D10, D11, D12: PGB1010603MRDIOC1608XV1; DIOC1608X36N
EPD_C1, EPD_C2, EPD_C6, EPD_C7, EPD_C8, EPD_C9, EPD_C10, EPD_C11, EPD_C12: 1uF/50V; EAGLE-LTSPICE_C0402
EPD_C5: 0.1uF/50V; EAGLE-LTSPICE_C0402
IC1: BD5229G-TR; SOT95P280X120-5N
IC4: XC6220A331MR-GSOT95P285V1; SOT95P280X120-5N
J1: FH34SRJ-24S-0.5SH_99_FH34V1; FH34SRJ24S05SH99
J2: SAMACSYS_PARTS_USB4110-GF-ASAMACSYSV1; SAMACSYS_PARTS_USB4110GFA
J3: QWIIC_RIGHT_ANGLE; JST04_1MM_RA
J4: 112A-TAAR-R03_ATTEND1123ATAARV1; 112ATAARR03ATTEND
L1: 744043680IND_4828-WE-TPC_WRE; IND_4828-WE-TPC_WRE
MPC73831: ESP32_WROVER_SPARKFUN-IC-POWER_MCP73831ESP32_WROO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; ESP32_WROVER_SPARKFUN-IC-POWER_SOT23-5
PFMF.050.1: ESP32C6_VARISTOR; ESP32C6_VARISTOR_CT/CN1812
Q1, Q2: 20V/4.2A/52mΩ/1.4W; ESP32_WROVER_SPARKFUN-DISCRETESEMI_SOT23-3
Q3: SI1308EDL-T1-GE3SOT65P21V1; SOT65P210X110-3N
R1, R1_PINH, R1_PINH1, R2_PINH, R2_PINH1, R4, R5, R6, R7, R8, R9, R10: 10K; ESP32_WROVER_EAGLE-LTSPICE_R0402
R1_BAT: 200; ESP32_WROVER_EAGLE-LTSPICE_R0402
R1_PWRUSB: 100K; ESP32_WROVER_EAGLE-LTSPICE_R0402
R2: 2.2; ESP32_WROVER_EAGLE-LTSPICE_R0402
R2_BAT: 2K; ESP32_WROVER_EAGLE-LTSPICE_R0402
R2_USB, R2_USB1: 5k1; ESP32_WROVER_EAGLE-LTSPICE_R0402
R3: 0.47; ESP32_WROVER_EAGLE-LTSPICE_R0402
RESET_BUTTON: BUTTON_CUSYOMV1; MYBUTTON
R_BOOT: 10K; ESP32_WROVER_EAGLE-LTSPICE_R0402
R_CAPACITOR: 15; ESP32_WROVER_EAGLE-LTSPICE_R0402
R_CHANGE: 10K; ESP32_WROVER_EAGLE-LTSPICE_R0402
R_CL1: 10K; ESP32_WROVER_EAGLE-LTSPICE_R0402
R_RESET: 10K; ESP32_WROVER_EAGLE-LTSPICE_R0402
SENSOR2: ESP32_WROVER_BME680_BME680ESP32_WROOM_BME680V1; ESP32_WROVER_BME680_PSON80P300X300X100-8N
SJ1: SJSJV1; SJ
TP1, TP2, TP3, TP4, TP5, TP6, TP7, TP8, TP9, TP10, TP11, TP12, TP13, TP14, TP15, TP16, TP17: TP; TP20R
U1: W25Q512JVEIQSON127P6V1; SON127P600X800X80-9N
U2: ESP32-C6-WROOM-1-N8XCVR_ESPV1; XCVR_ESP32-C6-WROOM-1-N8
U3: DS3231SN#SOIC127P1V1; SOIC127P1032X265-16N
U4: MAX17048G+T10SON50P20V1; SON50P200X200X80-9N

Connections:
3V3: C1_BAT2.1, C3.+, C9.1, D7.2 (ANODE), IC1.2 (VDD), IC4.5 (VOUT), J3.2, J4.P4 (VDD), Q2.3 (D), R1.2, R1_PINH1.2, R2_PINH1.2, R5.2, R6.2, R7.2, R8.2, R9.2, R10.2, R_BOOT.2, R_CHANGE.2, R_CL1.2, R_RESET.2, TP16.TP, U1.3 (!WP!(IO2)), U1.7 (!HOLD!/!RESET!(IO3)), U1.8 (VCC), U2.2 (3V3), U3.2 (VCC)
12C_PW: C1.1, C2.1, R1_PINH.2, R2_PINH.2, SENSOR2.2 (CSB), SENSOR2.6 (VDDIO), SENSOR2.8 (VDD)
32KHZ: R2_PINH1.1, U2.9 (IO1), U3.1 (32KHZ)
DN: D1.4 (I/O2_2), J2.A7, J2.B7
DP: D1.6 (I/O1_2), J2.A6, J2.B6
EPD_3V3: C7.1, EPD_C5.2, J1.15, J1.16, L1.2, Q2.2 (S), TP17.TP
EPD_3V3_C: Q2.1 (G), R_CL1.1, TP13.TP, U2.18 (IO20)
EPD_BUSY: J1.9, TP9.TP, U2.26 (IO3)
EPD_CS: D6.2, J1.12, R9.1, TP10.TP, U2.11 (IO10)
EPD_DC: J1.11, TP11.TP, U2.5 (IO5)
EPD_RST: J1.10, TP12.TP, U2.21 (IO23)
FLASH_CS: D9.2, R5.1, U1.1 (!CS), U2.12 (IO11)
GDR: J1.2, Q3.1 (G), R4.2
GND: BOOT_BUTTON.1, BOOT_BUTTON.2, C1.2, C1_BAT.2, C1_BAT1.2, C1_BAT2.2, C2.2, C2_BAT.2, C3.-, C4_USB.2, C5.2, C5_USB.2, C6.2, C7.2, C8.2, C9.2, C10.2, C10_SUPERCAP.1, CHANGE_BUTTON.1, CHANGE_BUTTON.2, C_DELAY.2, D1.2 (GND), D3.1 (K), D6.1, D8.1, D9.1, D10.1, D11.1, D12.1, EPD_C1.1, EPD_C2.1, EPD_C5.1, EPD_C6.1, EPD_C7.1, EPD_C8.1, EPD_C9.1, EPD_C10.1, EPD_C11.1, EPD_C12.1, IC1.3 (GND), IC4.2 (VSS), J1.8, J1.17, J1.MP1, J1.MP2, J2.A1, J2.A12, J2.B1, J2.B12, J2.MP1, J2.MP2, J2.MP3, J2.MP4, J3.1, J4.G1 (GND_1), J4.G2 (GND_2), J4.G3 (GND_3), J4.G4 (GND_4), J4.P6 (VSS), MPC73831.2 (VSS), R1_PWRUSB.1, R2.1, R2_BAT.1, R2_USB.2, R2_USB1.1, R4.1, RESET_BUTTON.1, RESET_BUTTON.2, SENSOR2.1 (GND), SENSOR2.5 (SDO), SENSOR2.7 (GND), SJ1.1, TP4.TP, TP5.TP, U1.2 (EXP), U1.4 (GND), U2.1 (GND), U2.28 (GND), U2.29_1 (GND), U2.29_2 (GND), U2.29_3 (GND), U2.29_4 (GND), U2.29_5 (GND), U2.29_6 (GND), U2.29_7 (GND), U2.29_8 (GND), U2.29_9 (GND), U3.13 (GND), U4.1 (CTG), U4.4 (GND), U4.6 (QSTRT), U4.9 (EP)
GPIO8: R1.1, U2.10 (IO8)
I2C_PW: U2.17 (IO19)
INT_RTC: R1_PINH1.1, TP15.TP, U2.8 (IO0), U3.3 (SQW/!INT)
IO/BOOT: BOOT_BUTTON.3, BOOT_BUTTON.4, C6.1, R_BOOT.1, U2.15 (IO9)
IO/CHANGE: C10.1, CHANGE_BUTTON.3, CHANGE_BUTTON.4, R_CHANGE.1, U2.23 (IO15)
MISO: D12.2, J4.P7 (DAT0), R8.1, TP6.TP, U1.9 (DO(IO1)), U2.27 (IO2)
MOSI: D11.2, J1.14, J4.P3 (CMD), R7.1, TP7.TP, U1.5 (DI(IO0)), U2.7 (IO7)
unnamed: J2.A5, R2_USB1.2
unnamed: C4.1, D3.2 (A), D4.1 (K)
unnamed: C_DELAY.1, IC1.5 (CT)
unnamed: CHG_LED.C, R1_BAT.1
unnamed: MPC73831.1 (STAT), R1_BAT.2
unnamed: J2.B5, R2_USB.1
unnamed: MPC73831.5 (PROG), R2_BAT.2
unnamed: EPD_C2.2, J1.5
unnamed: EPD_C1.2, J1.4
unnamed: EPD_C12.2, J1.24
unnamed: EPD_C10.2, J1.22
unnamed: EPD_C8.2, J1.20
unnamed: EPD_C7.2, J1.19
unnamed: EPD_C6.2, J1.18
unnamed: D7.1 (CATHODE), R_CAPACITOR.1
unnamed: D2.2 (ANODE), Q1.1 (G), R1_PWRUSB.2
unnamed: C1_BAT1.1, D2.1 (CATHODE), IC4.1 (VIN), IC4.3 (CE), Q1.2 (S)
PREVGH: D5.1 (K), EPD_C9.2, J1.21
PREVGL: D4.2 (A), EPD_C11.2, J1.23
RESE: J1.3, Q3.2 (S), R3.2
RESE': R2.2, R3.1, SJ1.2
RESET: C5.1, IC1.1 (VOUT), RESET_BUTTON.3, RESET_BUTTON.4, R_RESET.1, U2.3 (EN)
RTC_RST: U2.16 (IO18), U3.4 (!RST)
RX: TP2.TP, U2.24 (RXD0/GPIO17)
SCK: D10.2, J1.13, J4.P5 (CLK), R6.1, TP8.TP, U1.6 (CLK), U2.6 (IO6)
SCL: J3.4, R2_PINH.1, SENSOR2.4 (SCK), U2.20 (IO22), U3.16 (SCL), U4.7 (SCL)
SDA: J3.3, R1_PINH.1, SENSOR2.3 (SDI), U2.19 (IO21), U3.15 (SDA), U4.8 (SDA)
SRC: C4.2, D5.2 (A), L1.1, Q3.3 (D)
SS_SD: D8.2, J4.P2 (CD/DAT3), R10.1, U2.4 (IO4)
TX: TP1.TP, U2.25 (TXD0/GPIO16)
USB_D+: D1.1 (I/O1_1), U2.14 (IO13)
USB_D-: D1.3 (I/O2_1), U2.13 (IO12)
VBAT: C2_BAT.1, MPC73831.3 (VBAT), Q1.3 (D), TP3.TP, U4.2 (CELL), U4.3 (VDD)
VBUS: C1_BAT.1, C4_USB.1, C5_USB.1, CHG_LED.A, D1.5 (VBUS), MPC73831.4 (VIN), PFMF.050.1.2, TP14.TP
VRTC: C8.1, C10_SUPERCAP.2, R_CAPACITOR.2, U3.14 (VBAT)
VUSB: J2.A4, J2.A9, J2.B4, J2.B9, PFMF.050.1.1

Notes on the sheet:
USB C connector & ESD protection
Display Type Selector
E-Paper Display Header
RTC Module DS3231SN
SD0805S020S1R0
LDO Voltage Regulator
DMG2305UX-7
E-Paper Drive Circuit
EPD Power
Environmental Senson BME688
BME688
Test Pads
Qwiic / Stemma QT
SPI ESD Protection Lines
External NOR Flash 64MB
Voltage Supervisor + Reset & Boot / IO Button
Battery Charge Level
Li-Po Battery Charging Controller
SD Card
ESP32 C6

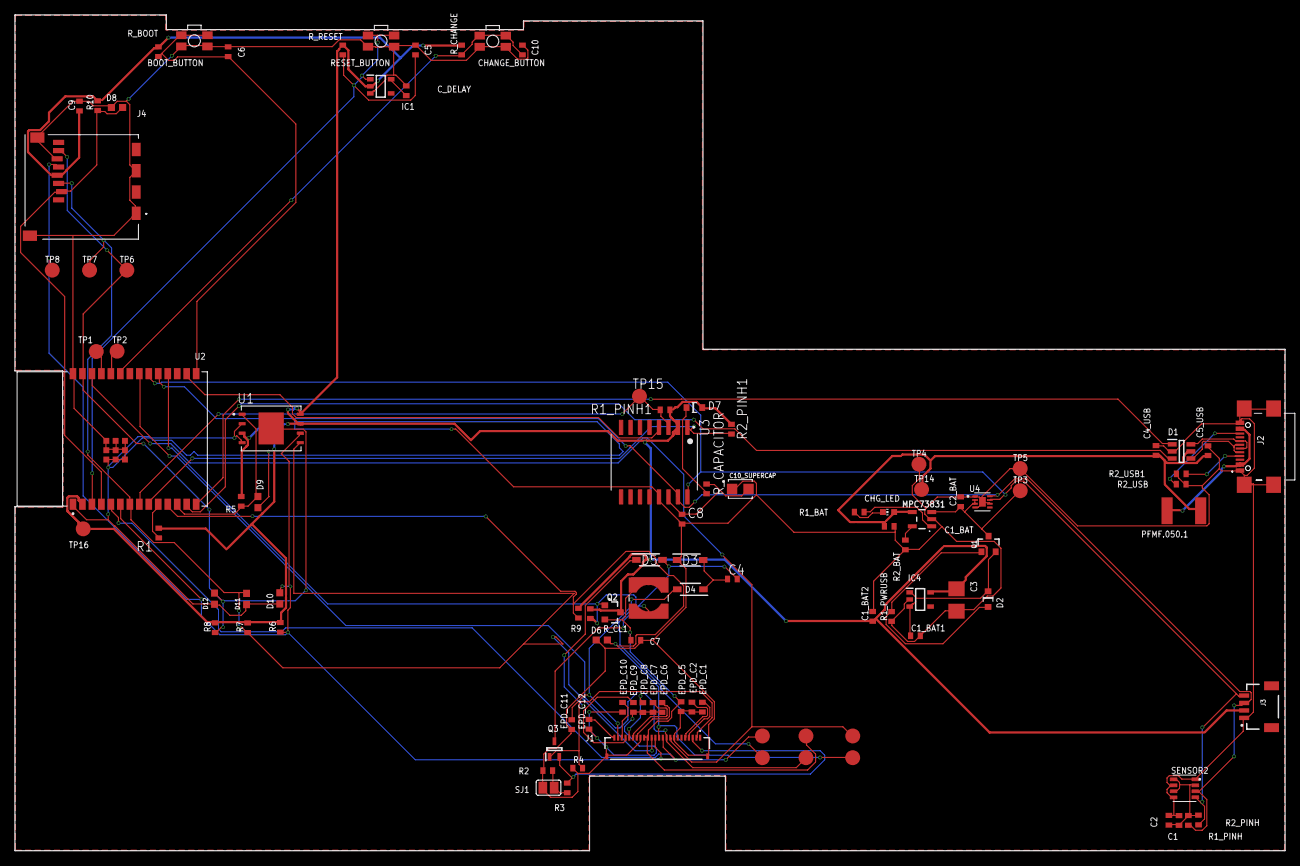
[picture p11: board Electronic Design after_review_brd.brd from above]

Board: 2 copper layers, 170.2 x 112.0 mm, 103 parts (0 on the bottom side), 56 nets.

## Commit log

2025-04-05 Github OpenBook Project Final Push
    [Electronic Design OpenBook Hardware v1.brd, Electronic_Design_OpenBook_Hardware_v1.sch, bom.csv]
2025-04-15 After review
    [Electronic Design after_review_brd.brd, Electronic_Design_after_review_sch.sch]
